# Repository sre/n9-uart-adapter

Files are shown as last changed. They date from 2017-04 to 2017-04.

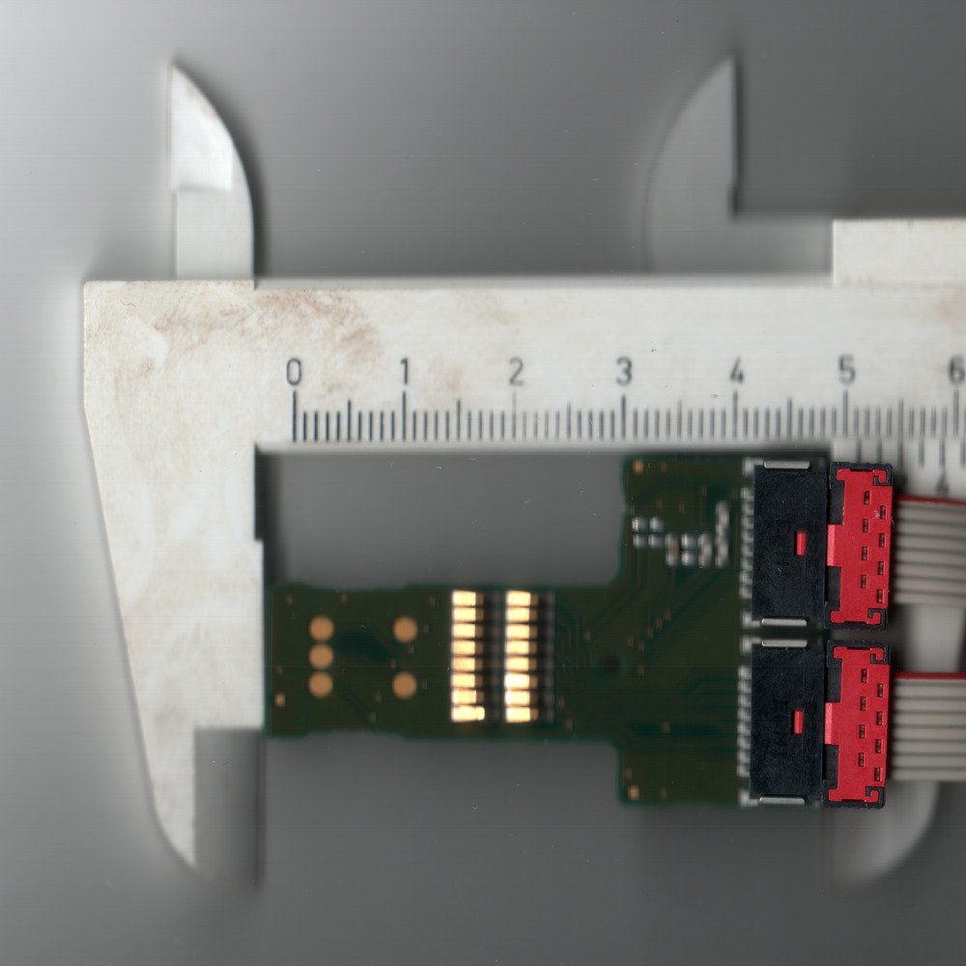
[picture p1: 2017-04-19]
images/original/scan2.jpg

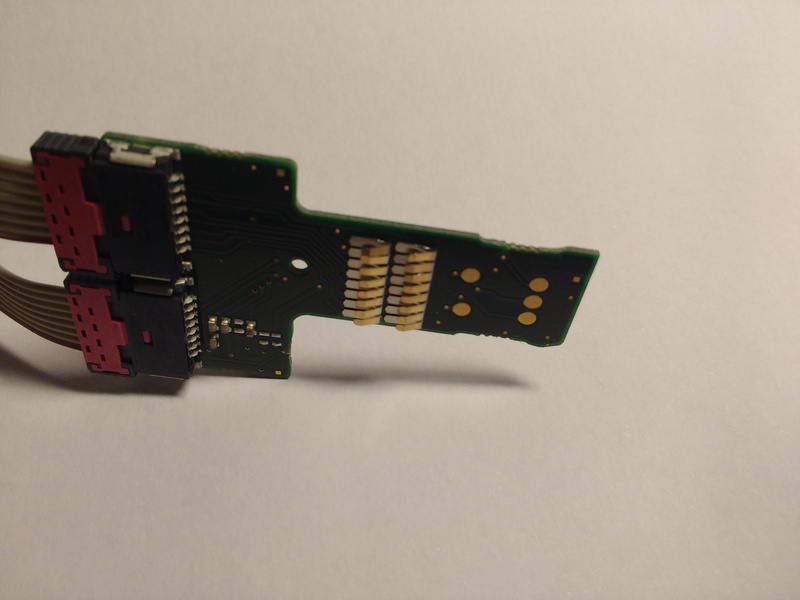
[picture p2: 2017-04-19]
images/original/uart1.jpg

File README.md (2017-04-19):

# N9 UART/Debug Adapter

Kernel developers like to have UART access to their embedded boards for
debugging purposes. While the Nokia N900 and N950 had the pads available
under their battery, Nokia N9 has them inside its SIM-card slot. This
project contains PCB design for KiCAD, which can be used to access the
UART pads.

To get the PCB into a functional state so called "spring fingers" must
be soldered to the rectangular pads.

# License

ISC License

Copyright (c) 2017 Sebastian Reichel <sre@kernel.org>

Permission to use, copy, modify, and/or distribute this software for any
purpose with or without fee is hereby granted, provided that the above
copyright notice and this permission notice appear in all copies.

THE SOFTWARE IS PROVIDED "AS IS" AND THE AUTHOR DISCLAIMS ALL WARRANTIES WITH
REGARD TO THIS SOFTWARE INCLUDING ALL IMPLIED WARRANTIES OF MERCHANTABILITY
AND FITNESS. IN NO EVENT SHALL THE AUTHOR BE LIABLE FOR ANY SPECIAL, DIRECT,
INDIRECT, OR CONSEQUENTIAL DAMAGES OR ANY DAMAGES WHATSOEVER RESULTING FROM
LOSS OF USE, DATA OR PROFITS, WHETHER IN AN ACTION OF CONTRACT, NEGLIGENCE
OR OTHER TORTIOUS ACTION, ARISING OUT OF OR IN CONNECTION WITH THE USE OR
PERFORMANCE OF THIS SOFTWARE.

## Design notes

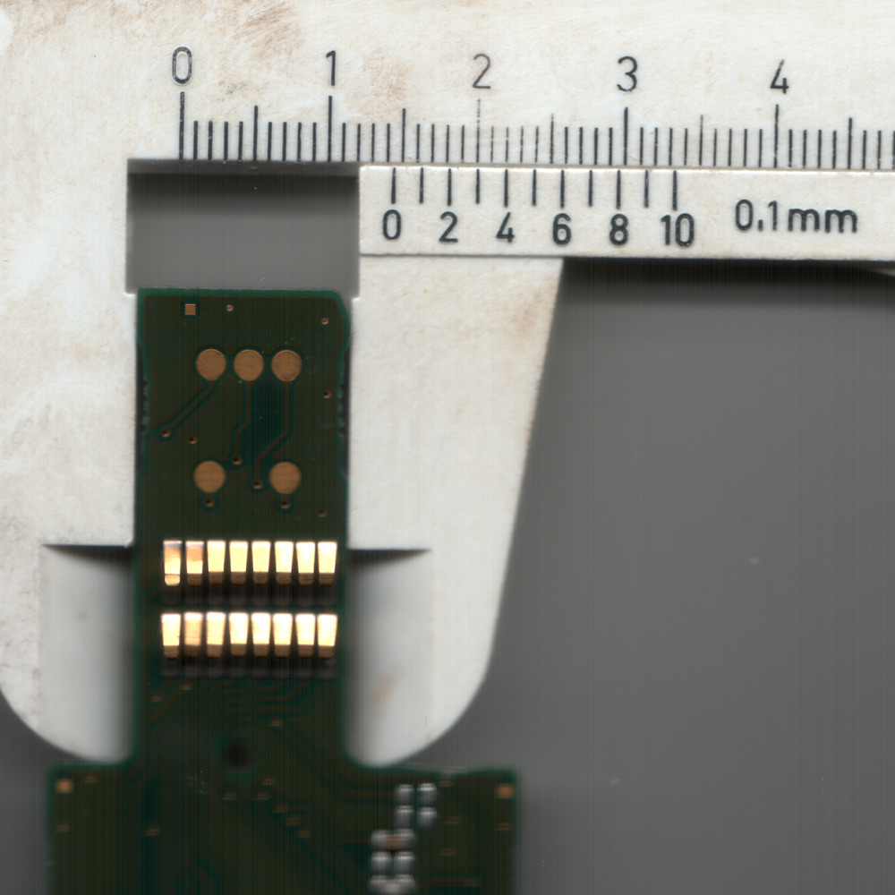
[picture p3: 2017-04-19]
images/original/scan1.jpg

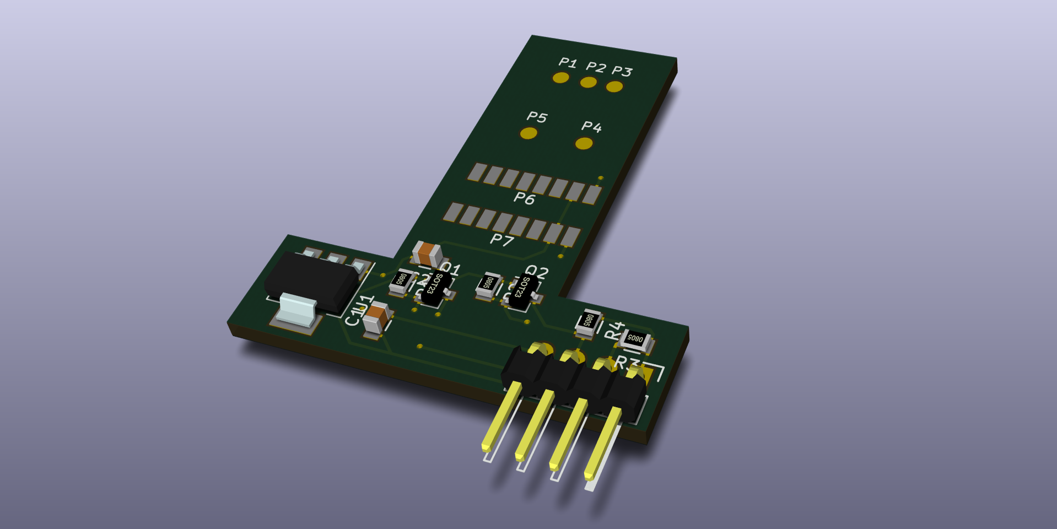
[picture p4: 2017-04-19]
images/clone/n9-uart-adapter.png

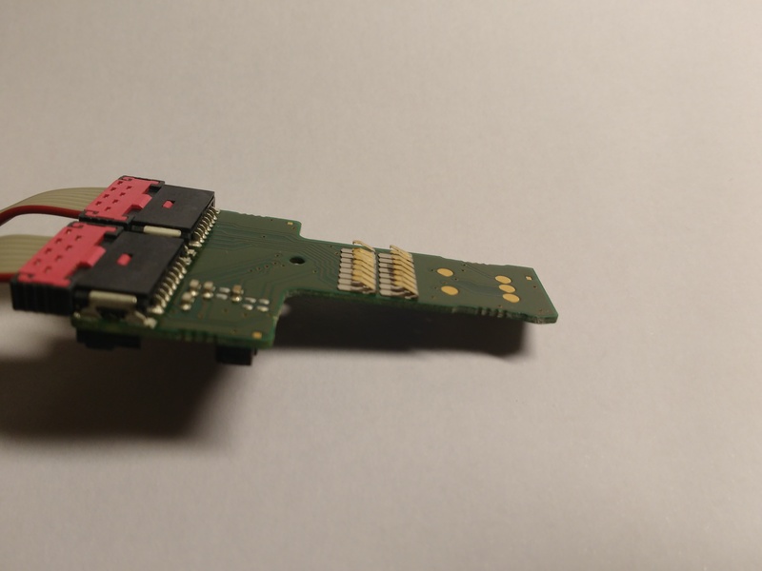
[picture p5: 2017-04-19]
images/original/uart2.jpg

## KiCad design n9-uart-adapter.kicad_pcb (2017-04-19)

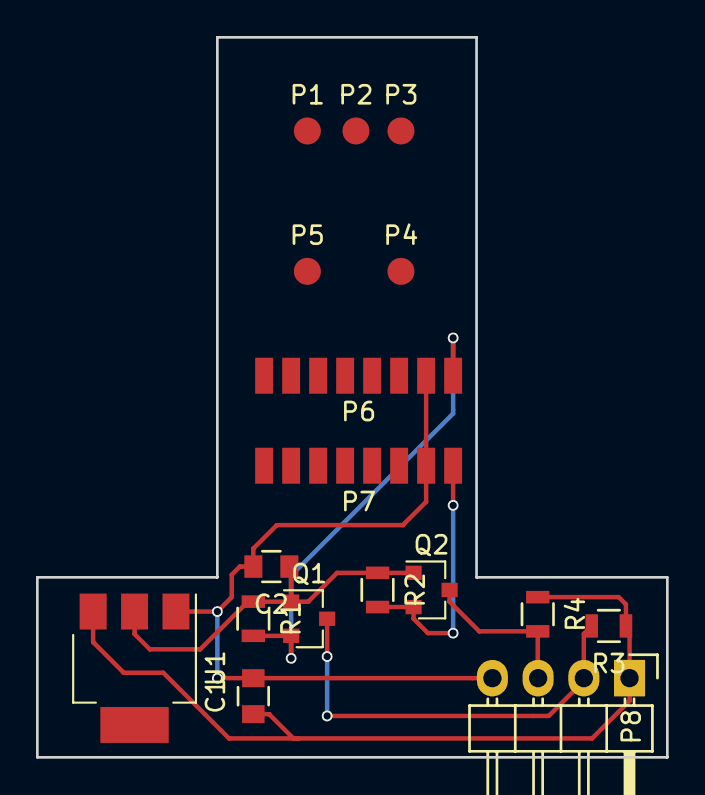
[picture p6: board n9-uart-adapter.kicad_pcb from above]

Board: 2 copper layers, 35.0 x 40.0 mm, 17 parts (0 on the bottom side), 7 nets.

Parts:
C1: 100nF; C_0805
C2: 10uF; C_0805
P1, P2, P3, P4, P5: PAD; Measurement_Point_Round-SMD-Pad_Small
P6: SPRING_FINGERS_1; Pad-Array
P7: SPRING_FINGERS_2; Pad-Array
P8: CONN_01X04; Pin_Header_Angled_1x04
Q1, Q2: BSS138; SOT-23
R1, R2, R3, R4: 10k; R_0805
U1: LD1117S18CTR; SOT-223

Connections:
+1V8: C2.1, Q1.1, Q2.1, R1.1, R2.1, U1.2
+5V: C1.1, P8.1, R3.1, R4.1, U1.3
/PC_UART_RX: P8.3, Q2.3, R4.2
/PC_UART_TX: P8.2, Q1.3, R3.2
/UART3_RX: P6.8, Q1.2, R1.2
/UART3_TX: P7.8, Q2.2, R2.2
GND: C1.2, C2.2, P6.7, P7.7, P8.4, U1.1
